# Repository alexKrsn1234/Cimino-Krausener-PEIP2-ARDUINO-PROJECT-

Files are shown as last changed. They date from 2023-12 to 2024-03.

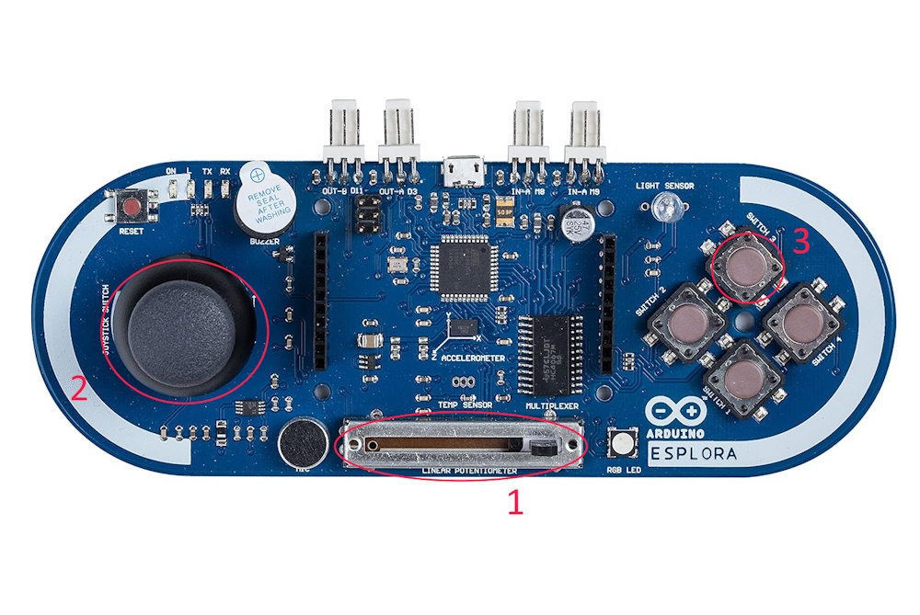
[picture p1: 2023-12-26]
documentation/Esplora Doc/images/esplora_buttons.jpg

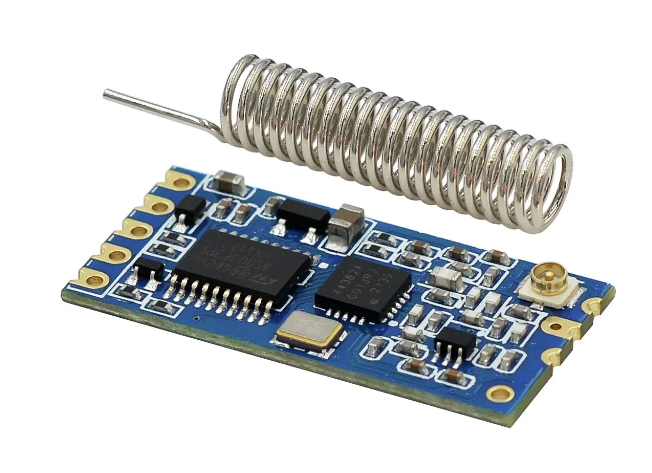
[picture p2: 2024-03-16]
documentation/HC-12 Doc/front.png

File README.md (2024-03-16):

# Cimino-Krausener-PEIP2-ARDUINO-PROJECT-
Ce projet est mené dans le cadre de la formation de PEIP2 de Polytech Nice-Sophia

## Cahier des charges
### Description: 
                  Voiture télecommandée rapide de type "RC Car".  
### Caractéristiques: 
                  -Roues avants directionelles
                  -4 roues motrices
                  -télécommunication RC

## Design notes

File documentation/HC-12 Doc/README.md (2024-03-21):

## QUICK HC-12 DOCSHEET


### PINS
   

Les pins VCC et GRD servent sans surprise à l'alimentation des modules.   
Les pins TXD et RXD eux permettent l'envoie d'information à travers le module.   
Le pin SET est utilisé pour configurer le module(mode, fréquence...).   

### CONFIG
Après avoir mis le pin "SET" à la masse, le module devrait être dans le mode "AT" prêt à recevoir les informations afin d'être paramétré (féquence, baud rate...)
Les différentes commandes utiles sont:   
  AT+Bxxxx pour modifier le baud-rate   
  AT+Cxxx pour modifier la chaine et ainsi la fréquence sur laquelle le module communique   
  AT+FUx pour modifier le mode de communication (délai d'envoie de bits, distance max de communication et optimisation de l'utilisation d'énergie)

### [Une documentation complète ici](https://statics3.seeedstudio.com/assets/file/bazaar/product/HC-12_english_datasheets.pdf)   

### [exemple d'utilisation trouvée sur le net](https://howtomechatronics.com/tutorials/arduino/arduino-and-hc-12-long-range-wireless-communication-module/)

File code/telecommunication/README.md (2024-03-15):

### Comment la télécommunication est-elle assurée ?

Celle-ci est assurée par les modules émetteurs/récepteurs Radio Fréquence HC-12. Ces modules se présentent comme ceci:   


Un des modules est placé sur l'arduino émetteur et l'autre sur l'arduino récepteur.
Le but final est d'envoyer le minimum d'informations afin d'éviter tout problème de surcharge des canaux, perte d'information... Il s'agit alors d'envoyer une 
valeur de vitesse visée de la voiture (roll) et de direction (direction)
L'ensemble des calculs nécessaires à la récupération de ces valeurs sont ainsi effectués côté émetteur avant leur envoi.
Les informations sont ensuite encodées au moment de l'envoi c'est à dire qu'elles sont serties de différents bits de contrôle.

Une fois réceptionées par l'arduino récepteur ces informations sont décodées et les valeurs reçues de roll et direction sont redirigées vers les pont en H. 

##### Détails techniques

fréquence: 433.4 MHz   
channel: 001   
baudrate: 9600

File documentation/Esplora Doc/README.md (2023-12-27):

# QUICK ESPLORA DOC SHEET

* ## Pins to use :  



* ## [Library](https://docs.arduino.cc/retired/archived-libraries/EsploraLibrary) to use.

* ## Buttons to use :  



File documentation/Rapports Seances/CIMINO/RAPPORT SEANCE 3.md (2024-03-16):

### Ce rapport est particulièrement long car il contient également le travail réalisé pendant les vacances de noël

# I/Travail réalisé pendant les vacances

##  I.1 MODULES HC-12

Découverte des modules et de leur fonctionnement, reconfiguration de ceci grâce aux commandes AT afin de communiquer sur une certaine fréquence(choix du canal)
à une certaine vitesse(baud rate) et du mode de fonctionnement(maitre/esclave, emmeteur/recepteur...).
Nombreux tests de communication effectués afin d'acquérir l'expérience nécessaire et de choisir un mode de fonctionnement paraissant adapté (les 3 premiers test 
ont étés réalisés sur 2 arduino uno (emmeteur/récepteur).
  1. envoie d'un bit d'information (0 ou 1)
  2. [contrôle à distance d'une led](/code/telecommunication/HC-12/HC12%20tests/ledtest)
  3. [envoie d'informations avec des bits de contôle (start, end)](/code/telecommunication/HC-12/HC12%20tests/TEST3)
     
  Emmetteur maintenant placé sur une Arduino Esplora   
  
  4. [envoie d'informations depuis le joystick de l'esplora](/code/test/car%20tests/esploratest/Joystick%20test)
  5. [envoie d'informations correctement encodées (bits de contrôles + bits liés au module d'envoie) à l'arduino uno du récepteur](/code/test/car%20tests/esploratest/Cytron%20motor%20test)

## I.2 HC-12 ET ESPLORA ET VOITURE

Définition d'un algorithme d'envoie/réception des données pour éviter les confusions.
Les valeurs envoyées sont les suivantes : Roll (enclenche le roulage du véhicule en fonction de la valeur de -255 à 255), Direction (décide de la valeur
de l'angle donnée aux roues avant de -255 à 255) et Communication (démarre une vérifiaction de la connexion).   

Les valeurs de Roll et de Direction sont calculées à l'aide des input de l'utilisateur. Ces calculs sont donc réalisés avant même l'envoie des données 
afin de priviliéger un envoie d'informations plus compacte.    

Ainsi, comme dans le [test 5](/code/test/car%20tests/esploratest/Cytron%20motor%20test), la valeur de roll est fonction de l'inclinaison du joystick(2) en Y et du slider(1), la valeur de direction dépend uniquement de l'inclinaison du joystick(2) en X.    

Ce sont ces données qui sont ensuite envoyées à l'arduino de la voiture par les modules RF HC-12.
Chaque envoie de données de l'esplora est certi de 2 bits de contrôle 's'(start) et 'e'(end) ainsi qu'un bit de séparation 'd'. 

Un envoie de données ressemble par exemple à "s120d58e", avec 120 pour la valeur de roll et 58 pour celle de direction.   

Une fois ces données reçues, l'HC-12 placé sur l'arduino de la voiture transmet ces données à l'arduino qui les "décrypte" et envoie l'infomation
nécessaire au pont en H qui contrôle les moteurs. Pour reprendre l'exemple précédent on demande au pont en H d'envoyer 120 au moteur 2 qui contôle 
la vitesse de la voiture et 58 au moteur 1(servo).  

La voiture semble lente, il faudra tester avec 2 ponts en H fonctionnels car je pense qu'avoir mis les 2 moteurs responsables de la vitesse de la voiture
sur la même sortie du pont en H divise le courant sortant de celui-ci en 2 (moteurs placés en parrallèles). Cela semble avoir un impact non négligeable
sur la puissance électrique reçue par les moteurs (divisée également par 2) et ainsi diminuant leur performance.

## I.3 POINTS A AMELIORER:

### 1. vitesse de la voiture:   

  Hypothèse: mettre 2 pont en H ou envoyer plus de patate

### 2. télécommunication:    

  -De nombreuses données semblent être perdues lors de la télécommunication   
  Hypothèse: Jouer sur les réglages des modules HC-12 afin de gagner en performance   
             Mettre des capacités en amont des modules comme recommandé   
             Changer de modules...    
             
  -Créer une vérification de la communication pour voir lorsque des données sont perdues (allumage led esplora)

### 3. branchements:
  -Réaliser des soudures pour simplifier les branchements réalisés et éviter les faux-contacts.   

## I.4 CREATION DE PLANS DANS LE BUT DE REALISER NOTRE PROPRE CHASSIS  

Nous avons décidé de prendre de l'avance sur la potentielle suite du projet en commençant à réaliser des plans 3D du futur chassis sur OnShape.
Alexandre réalisera l'ensemble de la partie transmission (Engrenages moteur, axe...) et les "suspensions" tandis que je tenterai de réaliser le bloc
chassis ainsi que l'aspect directionnel.

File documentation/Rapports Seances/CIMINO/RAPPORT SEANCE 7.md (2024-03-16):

## BUT DE LA SEANCE:
Le but que je m'étais fixé lors de cette séance était d'isoler la panne rencontrée la semaine dernière et de parvenir à la contourner.
Pour revenir un peu sur la panne, la voiture ne réagissait pas malgrè la bonne réception des données de la télécommande (côté emmeteur), il s'agissait donc
d'un problème côté voiture (code jusqu'à présent théorique, branchements ou composant(s) deffectueux). 

## TRAVAIL REALISE LORS DE LA SEANCE:
Afin d'isoler cette panne j'ai donc décidé de tester l'ensemble de la partie côté recepteur (code, branchements et composants). Afin de ne pas rajouter une potentiel nouvelle panne
j'ai décidé de ne pas travailler avec la télécommande mais d'implémenter directement le code nécessaire aux tests sur l'arduino de la voiture.
### Partie code:
Pour être sûr de la fiabilité de mon code, j'ai analyser chaque ligne de mon code ainsi que leur but et comparer avec le code de la séance de travail effectuée 
au cours du 1er semestre avec les ponts en H LN298N. Aucun problème de semblait venir du code. Les bons usages étaient respectés ainsi que les bonnes 
procédures. J'ai pu tester les fonctions [du code](/code/test/car%20tests/esploratest/L298n%20motor%20test/receiver/receiver.ino) sur une autre voiture et celui-ci fonctionnait convenablement. Le bug ne venait donc pas du code.

### Partie branchements et composants:
Dans le but de tester mes branchements et mes composants j'ai utilisé un multimètre principalement en tant que voltmètre afin de tester les tensions aux bornes de
ceux-ci. J'avais déjà des indcations visuelles (carte arduino bien alimentée car diode de contrôle alummée). J'ai alors testé les tensions en entrée et en sortie 
des ponts en H en implémentant des codes simples (ex : avancer en continue à fond, on est censé récupérer un haut voltage en sortie (out1,out2), le même qu'en entrée sur 
la patte enable. Lors de ce test je me suis rendu compte que les ponts en H étaient obsolètes. Ils ne fonctionnaient pas ou plus (impossible à déterminer) étant
donné qu'on avait jamais su les faire fonctionner (soit parce qu'ils étaient obsolètes initialement ou car nous les avions rendu hors service suite à une mauvaise
utilisation au départ). J'ai alors demandé de nouveaux ponts en H et était très précautioneux. Après les avoir branchés correctement (non sans mal car il s'agit 
d'un vrai travail d'orfèvre), j'ai réalisé à nouveau des tests qui se sont avérés fructueux. La panne provenait seulement des ponts en H. Nous pouvons reprendre 
l'avancement du projet.

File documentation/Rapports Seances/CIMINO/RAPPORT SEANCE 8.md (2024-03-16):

## TRAVAIL REALISE:
Lors de cette séance, je me suis attelé à faire fonctionner la voiture. Lors de la séance précédente nous avions résolu le bug qui empêchait la voiture de se
déplacer. Cette fois ci j'ai donc réalisé tout les branchements nécessaires pour l'utilisation des 2 ponts en H et j'ai donc testé le [code théorique](/code/test/car%20tests/esploratest/L298n%20motor%20test/receiver/receiver.ino)
réalisé il y a 2 seances auquel j'ai rajouté une fonction pour tourner. Le test se faisait donc à distance à l'aide de la télécommande. Le test a dans l'ensemble
porté ses fruits mais on a pu constaté certains bugs:   
  -La voiture n'a pas le même comportement en marche avant et en marche arrière.

  -Elle est capable de tourner que d'un seul côté.

  -Elle n'est pas capble de réaliser une marche arrière à pleine puissance.

  -Elle peut difficilement avancer et tourner en même temps.

Nous avons donc chercher des solutions pour palier à ces problèmes. Alexandre s'est penché sur la question et vous trouverez ses recherches dans son rapport de
séance. Finalement après de nombreux essais infructueux, nous avons décidé de charger pleinement la batterie (elle était à ~3,8V par cell) jusqu'à ~4,2V par cell.
Il semble alors que cette recharge soit la solution au problème. Une solution qui semble toutefois partielle car nous aimerions dans l'idéal que la voiture
remplisse ses fonctions pendant un maximum de temps d'utilisation. J'ai alors procédé à des tests pour déterminer jusque quel voltage la voiture est totalement 
opérationnelle. Cette valeur est atteinte pour METTRE LE VOLTAGE. Nous en avons donc conclu que METTRE UNE CONCLUSION.

J'ai également décidé de créer une pièce qui servirait de support pour placer l'ensemble de nos composants (jusqu'à présent plus ou moins bien entassés sur 
le chassis de la voiture) afin de rendre un travail plus propre et avec moins de risque de casse(faux-contacts...).

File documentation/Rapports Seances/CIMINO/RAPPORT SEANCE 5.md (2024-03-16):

## I/ Partie pratique et résumé:
Cette semaine mon travail consistait pleinement à mettre en fonctionnement la voiture avec la nouvelle batterie et les nouveaux ponts en H confiés pour l'occasion.   



Nous sommes passés d'une batterie 2 cells(7,4V) à une 3 cells(11,1V) dans le but d'acquérir plus de puissance. Cette batterie envoyant un débit plus élevé il s'agit
donc de mettre à l'épreuve de nouveaux ponts en H car le précedent devenait ainsi obsolète. Nous possédant désormais 2 ponts en H montés sur leur module LN298N.
Pour la sélection des ponts en H et de leur nombre nous avons effectué des test d'ampérage en entrée des moteurs. En roulage avec resistance infligée afin de 
simuler les forces de frottement et le poids de la voiture s'opposant au mouvement on obtient pour une tension d'entrée de 5V un ampérage totale en entrée des 
moteurs d'environ 2 ampères. Les modules LN298N pouvant sortir jusqu'à 1,2 ampères sans compromettre la sécurité, j'ai donc choisi d'utiliser 2 ponts en H.
Le premier s'occupera de la motorisation des roues et l'autre de la direction et du potentiel futur bras dont la création repose sur Alexandre.

Afin de pouvoir alimenter ces 2 ponts en H à l'aide d'une seule batterie, J'ai soudé à chaque fil + et -d'un connecteur XT60 qui sera relié à la batterie
2 fils qui se connecteront chacuns à leur borne respective des LN298N. Les ponts en H sont ainsi connectés en parrallèle à la batterie et alimenteront ensuite
les moteurs.   



## II/Partie code:

Afin de finir la mise en place de ces nouveux composants, j'ai réalisé le code théorique pour commander les moteurs de la voiture après avoir installé 
une librairie permettant de se servir facilement des fonctionnalités du LN298N. Cependant, je n'ai pas pu vérifier le bon fonctionnement du code (cf III).

## III/Problèmes rencontrés:

Il semblait à première vue que la batterie qui nous avez été confiée etait Hors Service. En effet après l'avoir mise en charge nous avons voulu la connecter 
afin de tester nos avancées, cependant elle ne fournissait pas le courant nécessaire pour alimenter l'arduino depuis le Pont en H. ALors j'ai testé son voltage
et celui-ci était de seulement 3V au lieu de 11,1 en moyenne. Après quelques recherches (étude de graphe du potentiel d'une 3 cell) j'en ai conclu que celle-ci
était hors d'état de service. J'ai donc demandé une autre batterie mais lors de la mise en charge, le même problème apparaissait c'est à dire que 
les leds du chargeur fournit clignotait en rouge, hors ce clignotement n'est même pas renseigné sur la docsheet du chargeur. La batterie ne charge pas.
Je me questionne donc sur l'état du chargeur et sur sa bonne compatibilité avec les batteries utilisées. Je n'ai pas résolu ce problème. Je tacherai de le 
résoudre avant la prochaine séance.

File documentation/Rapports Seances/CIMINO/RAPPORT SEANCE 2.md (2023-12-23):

#      SEANCE DU 22/12/2023 

Lors de cette séance j'ai été occupé par l'aspect télécommunication que recquiert notre projet. Il s'agissait alors de paramétrer les modules HC-12
qui nous ont étés confiés afin de réaliser la liaison entre la télécommande (Arduino esplora) et la voiture (commandée par l'arduino UNO).


J'ai alors paramétré les modules afin qu'ils communiquent sur les mêmes fréquences et qu'ils possèdent la même vitesse de transmission grâce aux commandes AT.
   
  -paramétrage de la vitesse de transmission entre les 2 modules:
    AT+Bxxxx avec xxxx vitesse de transmission des informations. J'ai choisi la valeur de 9600 bauds car je ne pense pas qu'utiliser 
    une valeur élevée soit une bonne idée, on risque de surcharger le canal et les cartes arduino alors que les moteurs de la voiture ne pourront pas suivre
    l'ensemble des ordes données à une telle vitesse car ils sont assujettis à une certaine inertie (je pense qu'il vaut mieux leur donner des valeurs "lissées 
    dans le temps"). Cette valeur pourra être modifier en fonction des résultats des expérimenttaions menées. 
  
  -paramétrage de la fréquence utilisée pour communiquer réalisé en choisissant la chaine sur laquelle communiquer:
    AT+Cxxx avec xxx numéro de chaine allant de 001 à 100 (001 correspond à une fréquence d'émission/réception de 433,4MHz elle augmente de 400KHz
    par augmentation de chaine). J'ai choisi arbitrairement le channel 050 mais encore une fois cette valeur pourra évoluer au cours du temps en fonction de 
    l'analyse empirique de la qualité de la télécommunication.

Ensuite, le but était de faire communiquer les 2 modules à distance.

Pour cela je me suis renseigner sur la documentation peu fournie du HC-12 pour établir un code établissant cette communication et la vérifiant.
Le but était d'envoyer des bits d'information 0 ou 1 d'un module à l'autre et de retranscrire les informations reçues sur le moniteur série de l'IDE Arduino.
Cependant malgrè de nombreuses tentatives, je n'ai pas réussi à faire passer une information d'un module à l'autre, je m'y atèlerai donc pendant les vacances.

Je suis alors parvenu à un programme à tenir avant la séance du 12 janvier:
* établir la communcation entre les 2 modules
* établir un protocole perfectionné d'envoie des bits pour envoyer des informations plus complexe sans confusion de données.
* connecter correctement un des modules à la télécommande (Arduino esplora) et récupérer conformément au protocole établie précedemment les informations
entrées par l'utilisateur de la télécommande.
* envoyer ces informations à l'autre module placé sur l'arduino uno (qui sera sur la voiture) selon le protocole.
* transférer les donées reçues et effectuer les actions demandées (donc nécessite un codage des informations selon le même
protocole définit précedemment).

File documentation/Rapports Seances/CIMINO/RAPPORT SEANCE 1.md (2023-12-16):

# SEANCE 1 (15/12/2023)
Après avoir terminé de définir clairement notre projet et nous être penché sur les performances que devront atteindre notre voiture (vitesse visée 50km/h).
Après également nous être renseigné sur la manière la plus optimal de réaliser la transmission arrière (point de départ de nos recherches) nous en avons déduit selon le raisonnement suivant:

Vvisée = 50km/h ~ 14m/s
diamètre roue D ~ 4,5 cm
1 tour de roue T= 2πR = πD = 4,5π cm ~ 14,1cm
Vroue = D/T ~ 100tr/s
gear ratio estimé : G=2 (2 tour de moteur pour 1 tour d'axe de transmission)
donc Vmoteur ~ 200 tr/s ~ 12000 tr/min

Il s'agissait donc de trouver une bonne combinaison batterie/moteur afin de faire tourner le moteur à environ 12000 tour par minutes.
Etant donné que nous ne sommes pas en mesure d'estimer les forces de frottements lors du roulage ainsi que le poids de la voiture nous avons pris la décision de prendre de la marge vis à vis des puissances des moteurs et des spécifications des batteries lors de nos recherches.

Lors de cette séance nous donc avons activement continuer les recherches (démarrées aupréalable) concernant les pièces dont nous  avons besoin pour mettre à bien notre projet.
Après avoir trouvé [batterie](https://www.amazon.com/dp/B08FM2MVNF/ref=emc_b_5_t), [servomoteur](https://www.amazon.com/gp/product/B07S9XZYN2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) et [esc](https://www.amazon.com/HOBBYWING-QUICRUN-10BL120-SENSORED-Touring/dp/B0765Q2SVS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,toys-and-games,116&sr=1-1&linkCode=sl1&tag=jinanprojec05-20&linkId=b2c1cea7d683851db009dc4553eaadb7&language=en_US&ref_=as_li_ss_tl), de mon côté nous avons mis en commun notre travail avec Alexandre pour discuter de nos choix de pièces et avons ensuite demander aux professeurs de passer commande. Le choix (définitif) de ces pièces nous permettait de nous lancer directement dans l'élaboration des plans du chassis (ainsi aux dimensions dictées par les composants).

Cependant Monsieur Masson a mis fin à nos espoirs en nous conseillant de travailler sur une voiture toute faite qu'il à mis à notre disposition.


L'idée initiale était de se concentrer uniquement sur l'aspect développement de notre voiture SEULEMENT sans inclure la partie télécommunication que nous comptions prendre "déjà réalisée".
Mais cette redirection nous pousse à abandonner l'ensemble de la partie conception et de nous rediriger sur les mouvements de la voiture et la télécommunication uniquement...

Il nous a donc été confié une Arduino [Esplora](https://docs.arduino.cc/retired/boards/arduino-esplora) afin de réaliser la télécommande ainsi qu'une paire d'emmeteur/recepteur.
Nous avons ensuite testé les moteurs de la voiture 1 par 1 afin de vérifier qu'ils fonctionnaient bien.

Cette redirection de projet innatendue nous a poussé à nous sortir de nos plans et de réenvisager l'ensemble de la suite du projet. Nous n'avons pas eu le temps d'aller plus loin dans notre réflexion lors de la séance. Cependant nous pensons qu'il est envisageable de terminer ce projet dans de courts délais afin de potentiellement revenir sur le projet initial.

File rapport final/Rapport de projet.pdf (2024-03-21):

# Rapport de projet: La voiture qui va vite

Un projet porté par Alexandre Krausener et Théo Cimino

## I/Objectifs du projet

L’objectif général du projet est de réaliser une voiture télécommandée dite « RC Car » qui roule à une vitesse élevée et qui a pour finalité d’être ludique. Il s’agit d’un jouet facile à utiliser afin de pouvoir plaire au plus grand nombre.
Afin de mener à bien ces objectifs nous avons défini un cahier des charges dans lequel des critères plus précis sont consignés.

I.a/Cahier des charges:
La voiture présente 4 roues motrices, dont 2 roues directrices (roues avants) et est télécommandée à longue distance. L’usage de la télécommande est intuitif et simple.

I.b/Objectifs associés:
Ce projet est l’opportunité pour nous de nous lancer dans la conception complète d’un produit, il nous offre la possibilité d’acquérir de l’expérience et de sérieuses compétences concernant l’organisation, la mise en œuvre et la réalisation d’une idée, en plus de développer nos talents en robotique.

## II/Plannings

Lors de la première séance nous avions conçu un planning prévisionnel afin d’anticiper et d ’évaluer le mieux possible les étapes de conception en terme de temps et d’investissement afin de proposer un déroulement idéal et optimisé du projet. Cependant malgré nos nombreux efforts tant à la conception de ce planning qu’à la réalisation de la voiture, celui-ci s’est avéré erroné et présente de multiples différences avec le planning final. Veuillez trouver ci-dessous les 2 plannings en question.
II.a/Planning prévisionnel: | II.b/Planning final:

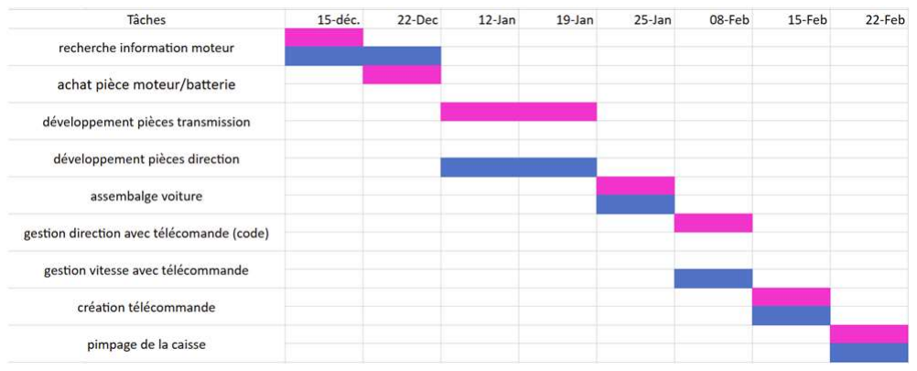
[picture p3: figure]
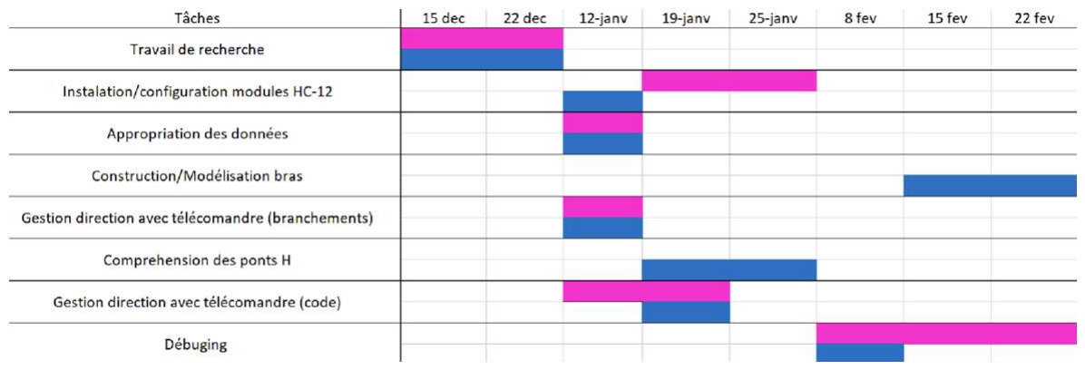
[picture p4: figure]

Les principales différences proviennent du fait de la redirection du projet, en effet, au départ nous comptions concevoir la voiture entièrement c’est-à-dire le châssis également. Cependant, la conception de ce châssis nous a été refusé alors toutes les tâches qui en découle ont été supprimées. De plus nous avons grandement sous-estimé la part de correction des erreurs et de débuging dans le planning prévisionnel.

## III/Fonctionnement de la voiture

III.a/Matériel utilisé
Le matériel auquel nous avons eu recours pour la réalisation du projet est le suivant: -1 châssis de voiture télécommandée -1 batterie 3 cells (11,4V) 2200mAh
-3 moteurs à courant continue
-2 pont en H
-2 modules émetteur/récepteur Radio Fréquence -1 Arduino uno
-1 Arduino esplora (télécommande) III.b/Schémas d’utilisation de la télécommande

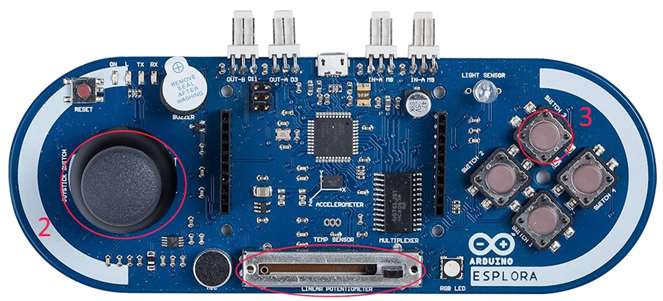
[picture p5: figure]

1: potentiomètre permettant de réguler la puissance des moteurs (20 à 100%)
2: joystick permettant de contrôler les mouvements de la voiture
3: bouton de vérification de l’état de la connexion entre la télécommande et la voiture

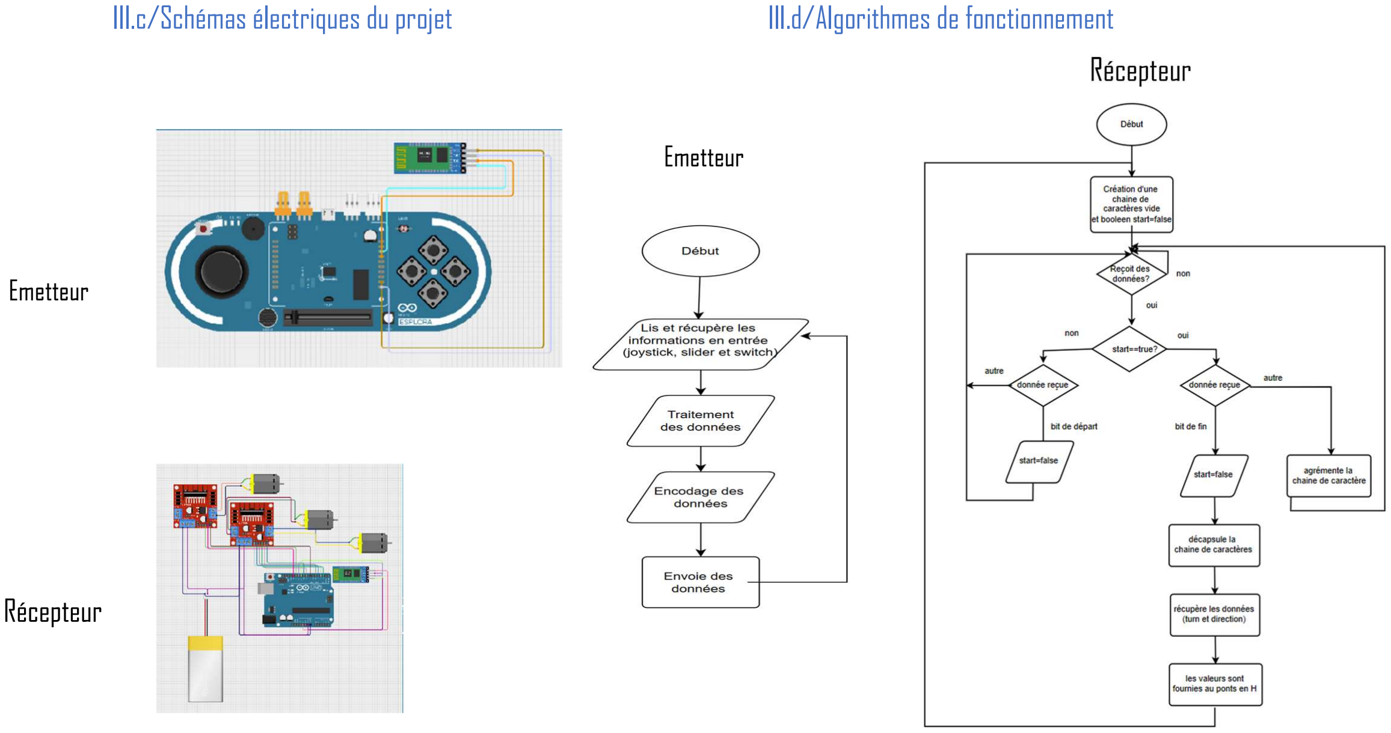
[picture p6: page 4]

III.c/Schémas électriques du projet | III.d/Algorithmes de fonctionnement

Emetteur

Emetteur

Récepteur

## IV/Estimation du coût

IV.a/Coût des composants et du matériel

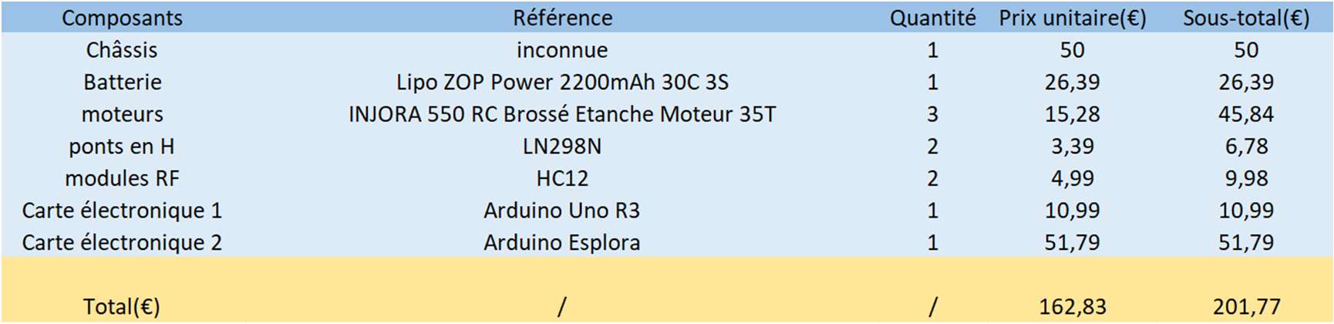
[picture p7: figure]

IV.b/Estimation de la masse salariale (Salaire d’ingénieur de 23€ de l’heure)

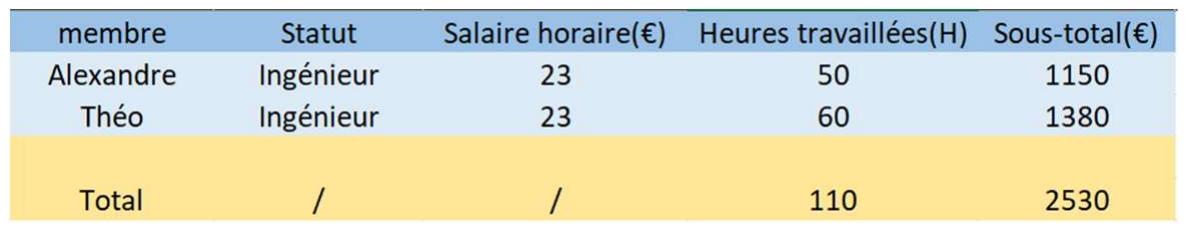
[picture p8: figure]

IV.c/Coût total
A l’aide de ces informations, le coût total est estimé à environ 2732€.

## V/Conclusion

V.a/Problèmes rencontrés
Le premier problème que nous avons rencontré est lié à l’obsolescence des drivers ch340 qui permettent la communication entre le pc et l’Arduino. En effet nous avons perdu de nombreuses heures à rechercher et réinstaller ces drivers quelque peu capricieux. Par la suite nous avons également étaient confrontés à de nombreux bugs après avoir décidé de changer l’alimentation de la voiture et ainsi de passer d’une batterie 2 cells à une 3 cells. Ce changement nous a valu d’augmenter le nombre de pont en H et de les changer ainsi de réadapter tout notre système d’alimentation. Ces changements ont induits de nombreux bugs tant informatiques (réécriture partielle des codes) que physique (courts circuits, batteries défectueuses…)
Malgré tout nous sommes parvenus au bout de ce projet. C’est-à-dire que nous avons conçu (mis à part le chassis) une voiture télécommandée dont le pilotage est simple et intuitif atteignant la vitesse astronomique de 10km/h sur le plat (alors imaginez en descente!!).
V.b/Perspectives envisagées
Dans le cas où il nous serait donner 8 semaines additionnelles pour continuer le projet il serait possible d’envisager au
moins 2 améliorations. Nous finaliserions certainement la conception de la pince (qui permet d’attraper des objets) que nous avions déjà envisager en fin de projet et nous nous pencherions également sur l’optimisation et la propreté de la conception c’est-à-dire d’envisager de créer nos propres PCB par exemple. Une autre perspective serait de tenter de concevoir le châssis de la voiture nous-mêmes comme initialement prévu. Ou même réaliser les PCB et le châssis pourquoi pas?

## VI/Bibliographie

L’ensemble de la bibliographie et des ressources utilisées se trouvent dans le dossier « documentation » du projet sous forme « nanani »Doc.

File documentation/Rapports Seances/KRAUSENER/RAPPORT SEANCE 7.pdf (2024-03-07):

RAPPORT SEANCE 7 :

Durant cette séance nous avons enfin réussi à faire avancer la voiture. En effet, en ayant changé la batterie, le pont en h n’était plus suffisant. Ainsi, nous avons dû tester les ponts en h car ils ne fonctionnaient pas correctement. Nous les avons donc branchés a la batterie et testé avec un voltmètre. Ils ne fonctionnaient pas du tout. Ainsi, M. Rallo nous en a donné d’autre et la voiture roule à nouveau !

De plus j’ai aussi avancé les plans du bras. Beaucoup de problèmes techniques concernant des mauvaises mesures ont donc étaient réglés (comprenant aussi la pièce imprimé la semaine dernière).

La semaine prochaine (dernière séance) il faudra imprimer toutes les pièces qui constituent le bars afin de le monter et de gérer branchements, assemblage et code.

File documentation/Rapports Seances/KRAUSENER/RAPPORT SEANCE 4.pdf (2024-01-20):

RAPPORT SEANCE 4 :

Durant cette séance, nous avons commencé à voir quels sont les objectifs réalisables dans le temps impartie par rapport aux idées énoncées la semaine dernière (bras télescopique, système de suivi de ligne…).

Avec mon collègue, nous avons déjà réussi à programmer et installer un radar capable d’arrêter la voiture si un obstacle se trouve devant elle.

Pour ma part, j’ai étudié les possibilités de la construction d’un bras. J’ai d’abord pensé à un système de fil pour descendre le bras et pour actionner les pinces. Néanmoins, avec ce système, nous ne parviendrons pas à attraper des objets lourds car c’est uniquement le poids des pinces qui feront résistance.

J’ai donc pensé à
un autre système
basé sur le
principe du tirebouchon
permettant
d’avoir plus de
force pour
attraper les objets
lourds et bloquer
les pinces.

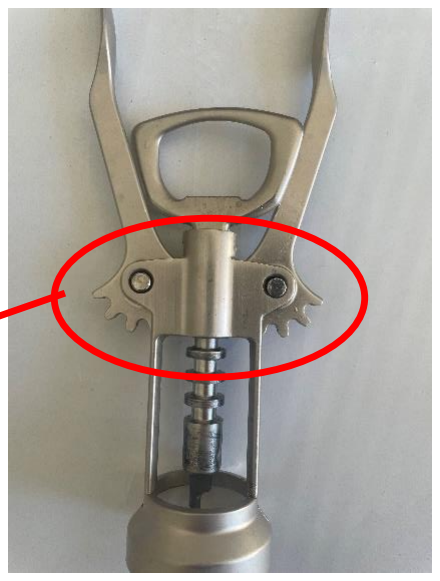
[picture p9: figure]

Il nous sera donc nécessaire d’avoir deux moteurs : un moteur classique semblable a celui qui gère la vitesse des roues et un piston qui gèrera les pinces.

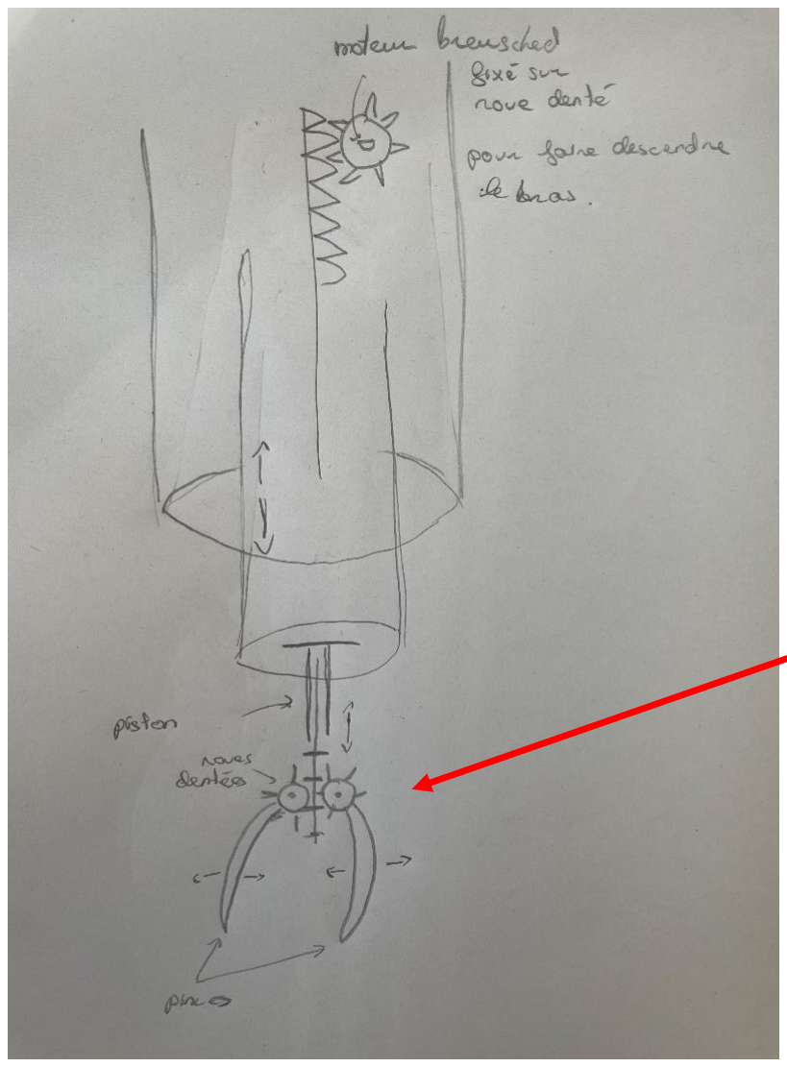
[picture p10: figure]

Le problème qui se pose est que désormais, trop de modules sont connectées au pont H, nécessitant alors trop de demande en tension. C’est pour cela que l’on nous a confié une batterie de 11,1 V. Mais, le pont H qui nous a été fournis n’accepte que du 9,5V. Un pont H admettant une plus haute tension sera donc nécessaire pour respecter un des points cruciaux du projet : rouler vite.

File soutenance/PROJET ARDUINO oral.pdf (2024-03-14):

# PROJET ARDUINO : LA VOITURE QUI ROULE VITE

Krausener Alexandre

Cimino Théo

## Sommaire :

## - Nos objectifs, nos motivations

## - Matériel utilisé

## - Explication du fonctionnement

## - Planning

## - Conception du bras

## MOTIVATION :

## OBJECTIFS :

## PROBLÉMATIQUE :

- Sujet distrayant
- Découverte de quelque
chose que tout le monde
connais
- Développer une voiture qui roule vite
- Tout construire de A à Z
- Comment construire un châssis ?
- Comment gérer la communication ?

# MATÉRIEL

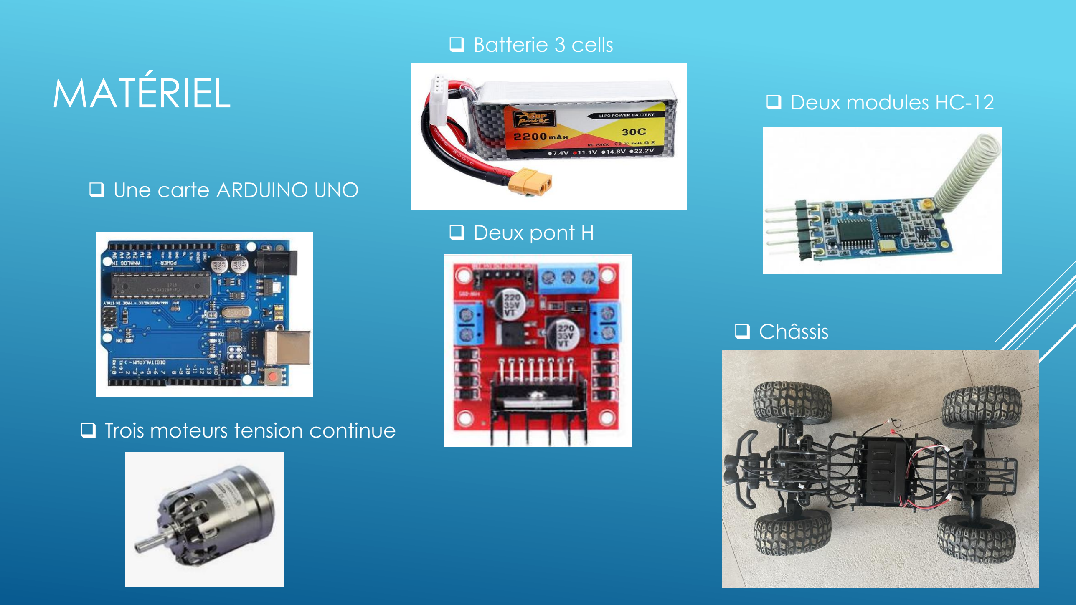
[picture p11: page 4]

❑ Une carte ARDUINO UNO

❑ Deux pont H

❑ Trois moteurs tension continue

❑ Deux modules HC-12

❑ Châssis

❑ Batterie 3 cells

# EXPLICATION DU PROJET

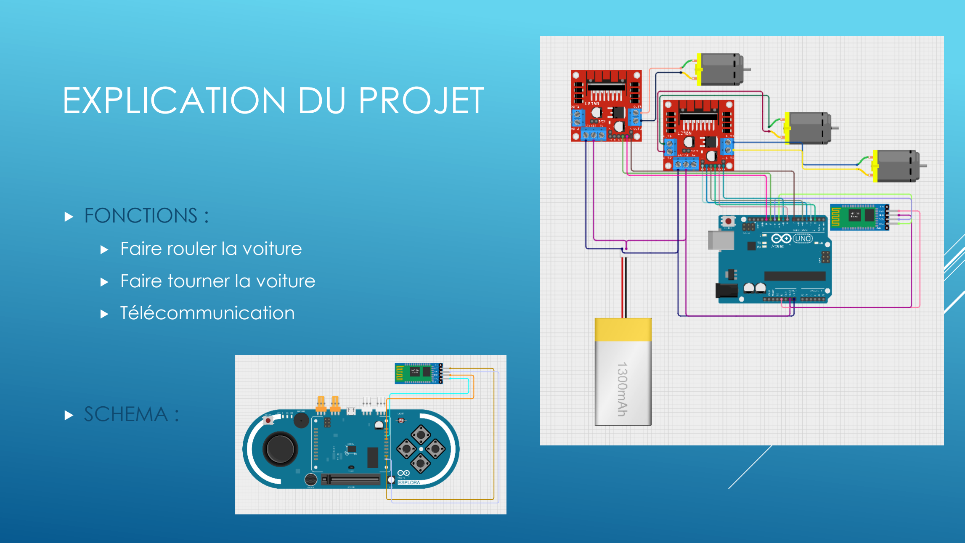
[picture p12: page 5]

- FONCTIONS :
- Faire rouler la voiture
- Faire tourner la voiture
- Télécommunication
- SCHEMA :

# PLANNING :

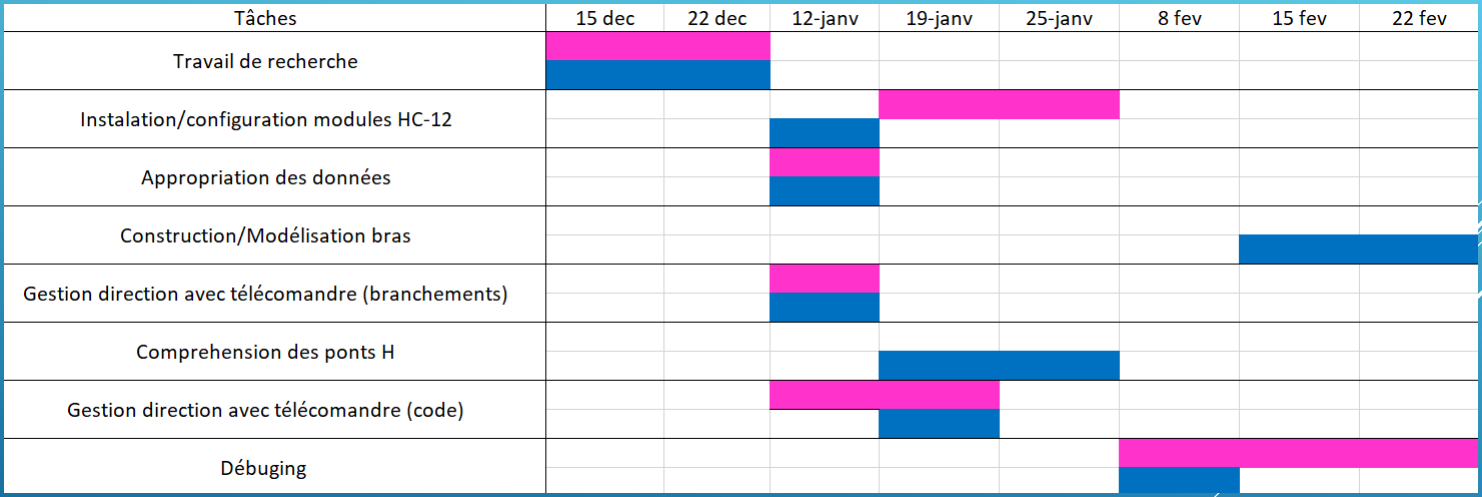
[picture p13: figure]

# CONCEPTION D’UN BRAS

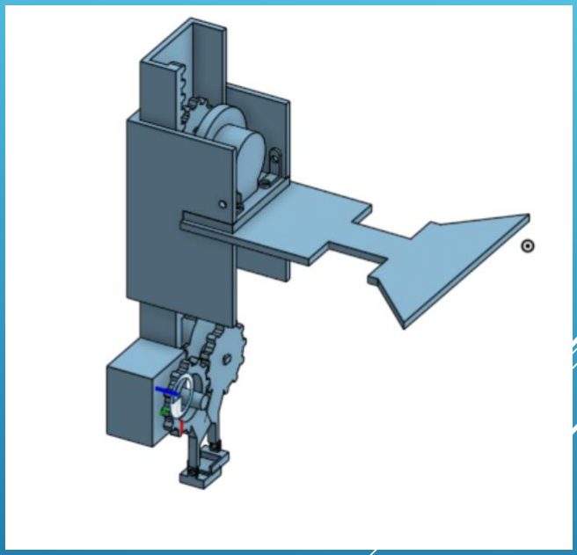
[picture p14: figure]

- Projet de bras : les deux dernières séances ont été consacrée à la conception d’un bras sur lequel est fixé une pince
1. Conception 3D
2. Impression 3D de certaines pièces

# CONCLUSION :

- C’est l’aboutissement d’un projet qu’on a porté pendant plusieurs semaines.
- On a développé nos compétences en Arduino, mécanique et en bricolage.
- On a appris à surmonter des difficultés et à renoncer à certaines idées non réalisables

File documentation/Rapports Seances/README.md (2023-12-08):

Ce dossier contient l'ensemble des rapports de séance de chacun des membres du binôme.

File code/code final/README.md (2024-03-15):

#### TADAAAA...Voici le dossier contenant les codes finaux, ceux avec lesquelles le projet est mené à bien (la voiture roule et vite)!

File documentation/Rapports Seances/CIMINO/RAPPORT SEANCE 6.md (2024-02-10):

## I/Problèmes rencontrés:
Les problèmes liés aux batteries fournies ont coûté plusieurs heures à l'avancement du projet. En effet, la première batterie récupérée avant la semaine de ski
s'est avérée être deffectueuse. J'ai pu la tester seulement au retour de la semaine de ski car je n'ai pas le matériel adapté chez moi et je n'ai pas pensé à le 
faire avant en cours (lors de la séance 5) pensant que le matériel ne serait pas deffectueux. Suite au test du voltage en sortie de la batterie, je me suis rendu 
compte qu'il ne sortait qu'environ 2,5V par cell contrairement à 3,7V minimum si celle-ci n'est que très peu chargée. J'ai alors demandé une autre batterie 3 cell
mais celle-ci posait le même problème, la rendant HS. Elle s'est même étonnemment déformée (gonflement anormal) la rendant dangeureuse (risque d'explosion).
La troisième batterie s'est avérée être en bon état. Mais la perte de temps est considérable. Tout le travail que je comptais réaliser pendant la semaine de ski
reposait sur l'utilisation de la batterie. Le projet a donc repris son cours lors de cette séance.

## II/Travail réalisé lors de la séance:
J'ai alors réalisé tout les branchements nécessaire pour tester le code théorique écrit à la seance précedente. Ce code visait à remplacer la version 1 du code 
fonctionnel côté recepteur car on a changer de pont en H en même temps que de batterie. L'ancien pont en H étaient obsolète pour une telle puissance délivrée (cf
RAPPORT SEANCE 5). Dans ce code j'ai utilisé une librairie conçut pour faciliter l'usage des ponts en H LN298, cependant malgrè les tests effectués, la voiture
ne se déplacait pas. En isolant le problème, je me suis rendu compte que les ponts en H ne délivraient pas la puissance aux moteurs. L'hypothèse est que le bug portet sur la librairie utilisée. J'ai donc décidé de ne pas utiliser cette librairie et de créer les fonctions dont j'ai besoin par moi même. J'ai donc codé
deux fonctions simple pour faire avancer et tourner la voiture en fonction des données reçues. Et j'ai remplacé les fonctions de la librairie par celles-ci. Le problème persiste cependant pour le moment.

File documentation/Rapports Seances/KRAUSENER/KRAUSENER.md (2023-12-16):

RAPPORT SEMAINE 1 (15/12/23) :
    Nous avons recherché plusieurs élements afin de réaliser notre projet. J'ai tout particulièrement recherché un moteur et commencé à comprendre comment celui-ci entrainait les roues. Dans l'optique de créer de toute pièce notre voiture RC, il fallait aussi s'interresser aux engrenages (la courroie de transmission), placés entre le moteur et les roues. J'ai alors cherché sur youtube comment certains avaient réussit à créer des voiture RC. Mais finalement, après avoir pris conseil auprès d'un enseignant, un chasis déjà fini nous à été confié. Nous avons donc déjà pu comprendre les branchements à effectuer sur notre voiture et commencé à coder pour aire avancer celle-ci.

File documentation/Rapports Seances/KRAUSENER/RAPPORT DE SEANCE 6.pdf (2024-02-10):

RAPPORT DE SEANCE 6

Durant cette semaine j’ai surtout travaillé sur les plans du bras robotisé.

J’ai ainsi déjà imprimé le support du bras (voir rapport séance 5) et avancé les plans.

Cette semaine, j’ai donc réalisé trois pièces supplémentaires : la courroie (indispensable pour faire monter et descendre le bras), la fixation pour cacher le moteur…) et l’engrenage pour faire la liaison entre le moteur et la courroie.

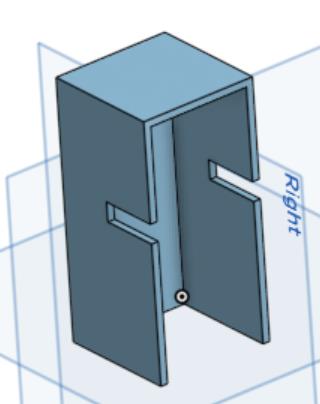
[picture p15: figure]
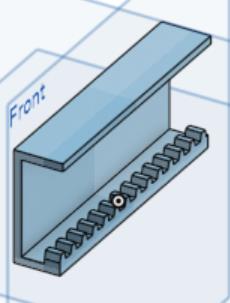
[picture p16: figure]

Assemblé, voici à quoi ça pourrait ressembler :

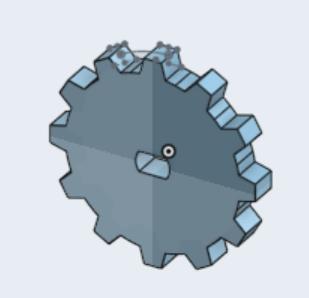
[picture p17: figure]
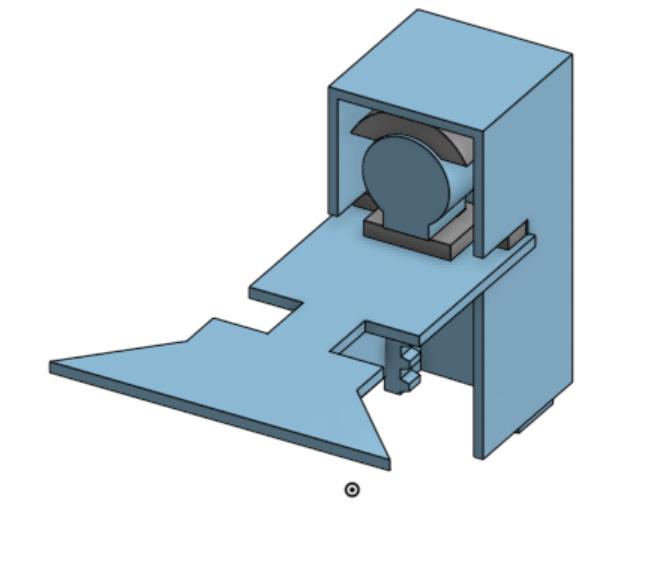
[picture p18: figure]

La suite du projet portera sur les pinces et le support pour le moteur les contrôlants ainsi que sur l’impression des différentes pièces.

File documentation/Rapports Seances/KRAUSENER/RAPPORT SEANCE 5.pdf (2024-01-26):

RAPPORT SEANCE 5

Durant cette semaine je me suis donc intéressé à la modélisation du bras et à sa conception.

J’ai tout d’abord expliqué mon idée à M. Masson qui m’a donc remis un moteur coup par coup pour faire baisser la courroie et donc faire baisser le bras. (Voir schéma séance 4)

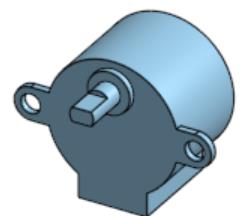
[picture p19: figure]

J’ai ensuite pu m’attaquer à la modélisation 3D sur le logiciel Onshape.

En cherchant sur internet, j’ai réussi à trouver des plans techniques du moteur et j’ai ainsi pu le modéliser en 3D avec les bonnes côtes sans difficultés.

J’ai ensuite cherché à savoir où je pouvais installer le bras et où placé la planche de maintient qui soutiendra la structure et les deux moteurs (moteur pas à pas et piston).

L’arrière de la voiture me semble un bon emplacement au vu de la place libre. C’est donc ce choix qui a donné lieu à la pièce que vous voyez ci-dessous. Comme des bouts de plastique gênent sur les côtés, j’ai donc dû prendre des mesures afin de faire des entailles à la structure pour qu’elle épouse parfaitement la forme de la voiture.

Bien sûr des perçages sont à prévoir pour fixer la structure à la voiture.

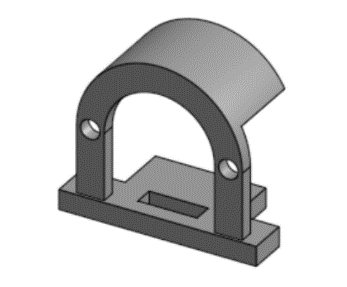
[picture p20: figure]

J’ai finalement aussi réalisé une pièce de fixation pour le moteur afin qu’il ne bouge pas lors du déplacement de la voiture. Vous pouvez également observer des trous sur la planche et l’accroche afin de faire passer les câbles du moteur.

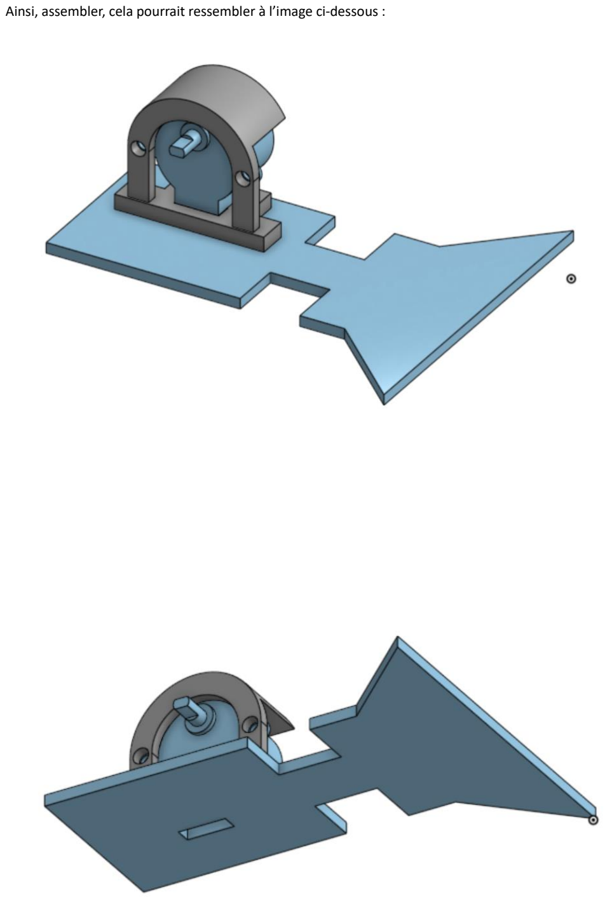
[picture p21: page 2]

Ainsi, assembler, cela pourrait ressembler à l’image ci-dessous :

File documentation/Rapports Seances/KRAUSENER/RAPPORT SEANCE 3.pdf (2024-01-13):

RAPPORT SEANCE 3 :

Durant les vacances, nous avons beaucoup progressé sur notre projet vu que notre voiture roule maintenant sans accros (Démo dans une petite stories Insta).

Un travail sur de multiples aspect à été fournis aussi bien par mon collègue que par moimême.

Pour ma part, je me suis concentré sur la manette ESPLORA et sa librairie associée.

La carte est relativement simple d’utilisation, mais, l’absence de documentation concernant les branchements des pins à rendu la tâche complexe.

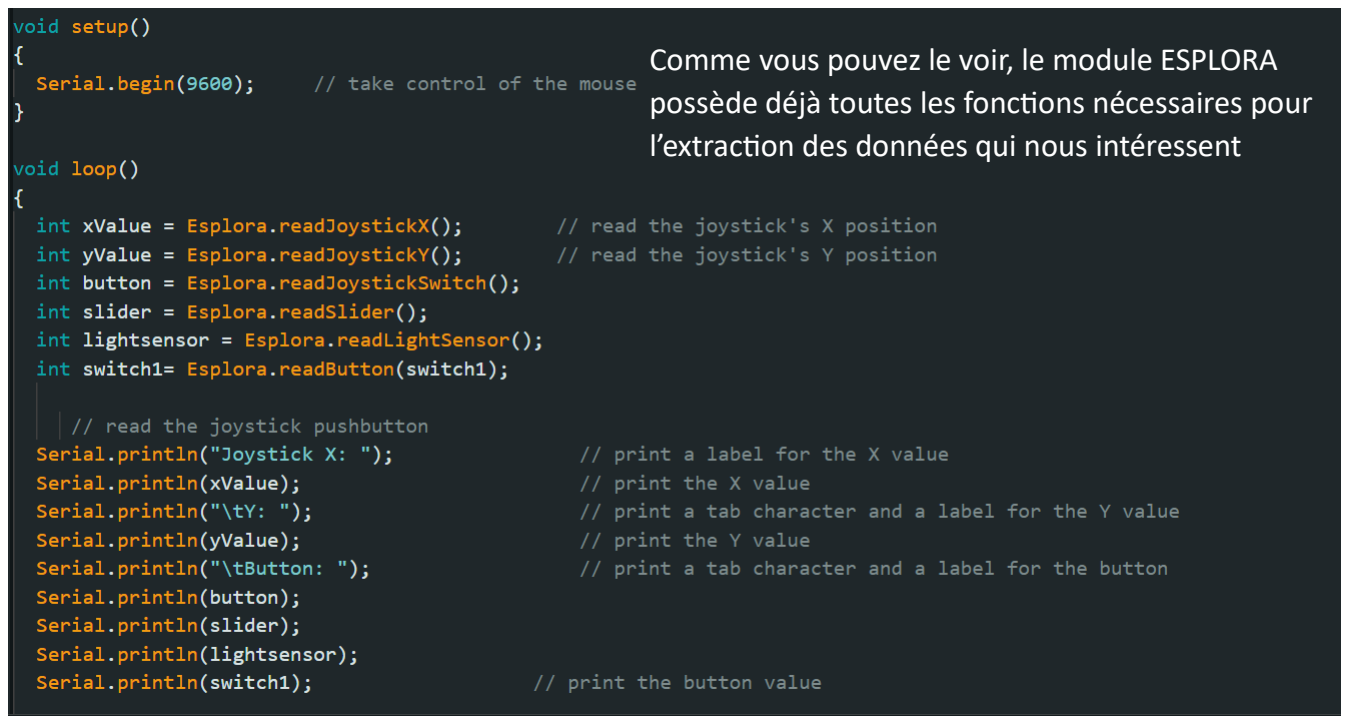
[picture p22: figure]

Après quelques recherches, j’ai trouvé une documentation non-officielle qui semble fonctionner.

J’ai donc ensuite procédé à des tests permettant de récupérer les informations données par les différents modules de la télécommande.

Voici les modules que nous allons utiliser :

1- Potensiomètre : ajuste la puissance délivrée aux moteurs
2- Joystick : gèrre la direction de la

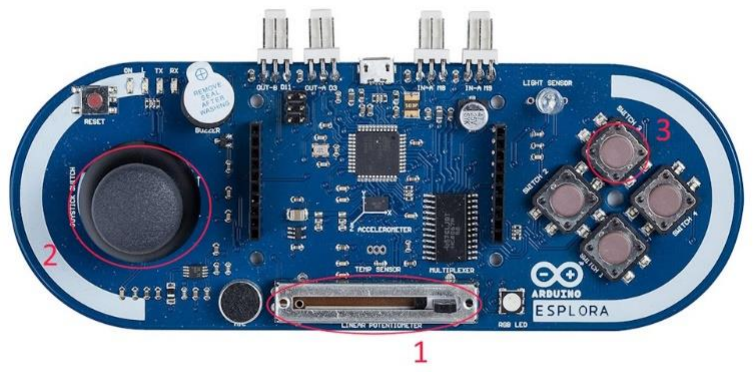
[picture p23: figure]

voiture
3- Bouton poussoir : verifira la connexion avec la voiture pour connaitre l’état de la transmission entre la télécommande et la voiture. (allumra une led si la connexion est bonne).

Comme vous pouvez le voir, le module ESPLORA possède déjà toutes les fonctions nécessaires pour l’extraction des données qui nous intéressent

Un câble management a aussi été réalisé pendant la séance grâce à des scratchs, diminuant alors drastiquement les faux contacts, problème qui a été relevé par mon collègue dans le rapport de séance 2.

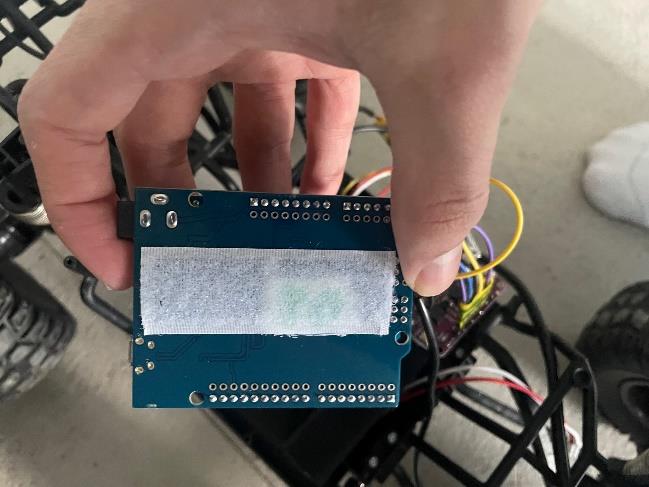
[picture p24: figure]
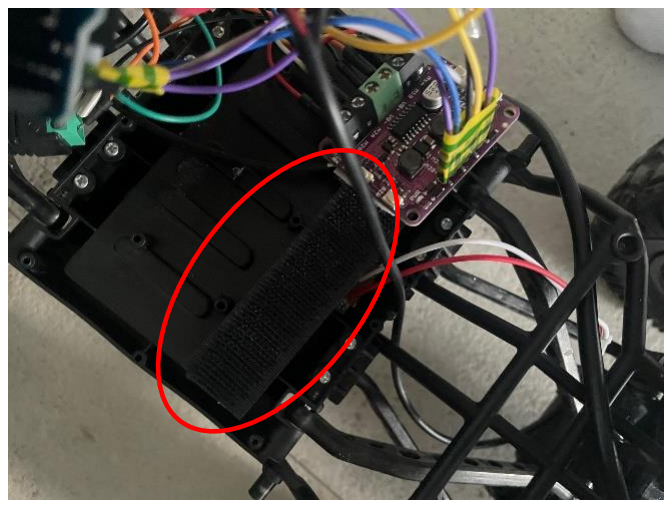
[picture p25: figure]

Durant la séance, un travail de recherche à été mené sur les possibilités d’amélioration de la voiture. En effet, vu qu’un châssis monté de toute pièce n’a pas été possible au vu du temps restant, plusieurs idées pourraient être implémentées dans les semaines à venir :

1- Système anticollision qui arrêtera la voiture si elle détecte un obstacle devant elle 2- Système de suivi de ligne pour une conduite autonome
3- Bras télescopique (à voir au vu du temps restant)

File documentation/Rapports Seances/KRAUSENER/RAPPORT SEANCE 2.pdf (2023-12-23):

## RAPPORT SEANCE 2 :

Durant cette semaine, nous avons beaucoup avancé, plus que les objectifs que nous nous étions fixés. Le travail a été judicieusement partagé entre mon collègue et moi, lui s’est occupé des modules HC-12 et je me suis intéressé au fonctionnement des moteurs/cerveau moteur et à leur utilisation.

En effet, la semaine dernière, un châssis déjà monté nous avait été donné et cette semaine a donc été consacrée à la compréhension du fonctionnement de tous les éléments constituants la voiture (moteur, pont H, émetteur /récepteur HC-12…).

J’ai, personnellement, réalisé les branchements des deux moteurs et du cerveau moteur au pont H et à la carte Arduino Uno.

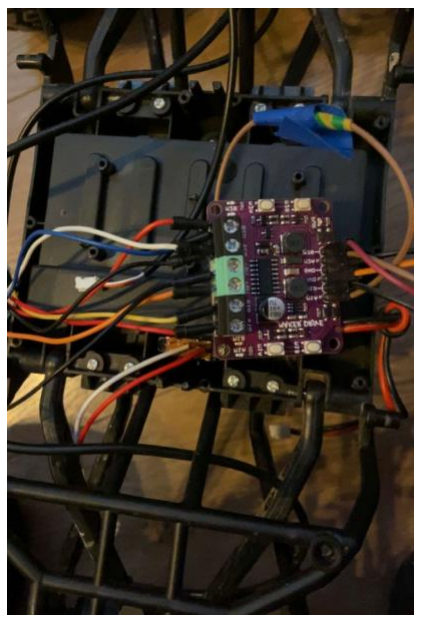
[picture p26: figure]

Durant le branchement, une erreur de ma part (mauvais branchement du pont H à la batterie) a causé la surchauffe d’un composant de celui-ci. Heureusement, Monsieur Masson nous avait confié deux d’entre eux. Ainsi, cette erreur n’a pas eu d’impact sur l’avancée du projet.

En séance, j’ai écrit le code nécessaire pour faire avancer la voiture sans télécommande (petit code qui fait avancer la voiture à 50% de sa capacité pendant 2 secondes puis qui l’arête pendant 3 secondes).

Initialisation des moteurs; Fonction faisant tourner les moteurs (valeurs allant de -255 à 255)

Concernant le récepteur/émetteur, j’ai réalisé les soudures de l’antenne et des pattes malles au composant afin de pouvoir l’utiliser sur la carte Arduino. Etant la toute première soudure que j’ai réalisée dans ma vie, l’aide du personnel du Fablab a été d’une grande utilité.

L’objectif des prochains jours/semaines, sera d’établir une liaison entre l’Arduino et la manette grâce au module HC-12 et du travail de Theo. Une fois les modules liés, la télécommunication entre la voiture et la télécommande sera simple à réaliser puisque, aussi bien de son côté que du miens, les notions


nécessaires ont été comprises. La tâche complexe sera donc, vous l’aurez compris, de lier les deux modules et de transmettre les informations.

Une fois cette tâche achevée, un travail de calibrage et de répartition du poids de la voiture sera nécessaire au vu de l’objectif fixé : aller vite.

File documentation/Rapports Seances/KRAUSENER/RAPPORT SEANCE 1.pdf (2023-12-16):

KRAUSENER Alexandre G1 PeiP2

## RAPPORT SEANCE 1 (15/12/23) :

Pendant cette séance, nous avons passé beaucoup de temps pour chercher des pièces. Personnellement, j’ai cherché un moteur capable de délivrer la vitesse nécessaire pour faire avancer notre voiture et répondre à notre cahier des charges.

Le moteur présenté ici pouvait satisfaire nos attentes puisque, voulant faire avancer notre voiture à plus de 30km/h, la force d’entrainement du moteur (P=F x V sans prendre en compte le poids de la
voiture et les frottements) est assez élevée.
Après | avoir | effectué
quelques recherches, nous
avons demandé à un
enseignant de commander
les pièces nécessaires pour la conception de de notre
voiture RC.


Cependant, notre enseignant nous à déconseiller de réaliser nous-même notre voiture car la direction poserait des problèmes techniques trop complexe à résoudre (présence d’un différentiel, pèces mécaniques technique…). Nous avons donc reçu un châssis déjà réaliser.


Celui-ci est composé de deux moteurs, un cerveau moteur et de toutes les pièces mécaniques nécessaire pour faire tourner notre véhicule. L’objectif des prochaines séances sera donc de comprendre comment faire avancer la voiture, effectuer les branchements, et de gérer la communication avec la télécommande fournie elle aussi.


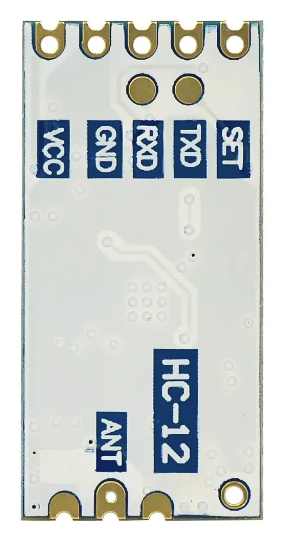
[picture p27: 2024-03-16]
documentation/HC-12 Doc/pins.png

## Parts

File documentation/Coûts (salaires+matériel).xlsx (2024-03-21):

Composants | Référence | Quantité | Prix unitaire(€) | Sous-total(€) | membre | Statut | Salaire horaire(€) | Heures travaillées(H) | Sous-total(€)
Châssis | inconnue | 1 | 50 | 50 | Alexandre | Ingénieur | 23 | 50 | 1150
Batterie | Lipo ZOP Power 2200mAh 30C 3S | 1 | 26.39 | 26.39 | Théo | Ingénieur | 23 | 60 | 1380
moteurs | INJORA 550 RC Brossé Etanche Moteur 35T | 3 | 15.28 | 45.84
ponts en H | LN298N | 2 | 3.39 | 6.78 | Total | / | / | 110 | 2530
modules RF | HC12 | 2 | 4.99 | 9.98
Carte électronique 1 | Arduino Uno R3 | 1 | 10.99 | 10.99
Carte électronique 2 | Arduino Esplora | 1 | 51.79 | 51.79
Total(€) | / | / | 162.83 | 201.77

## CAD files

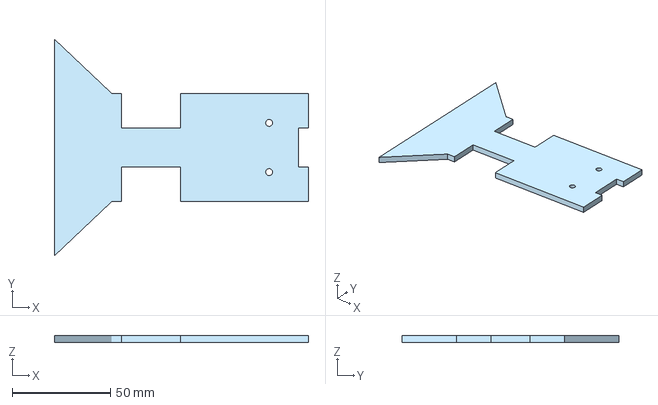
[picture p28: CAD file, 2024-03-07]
3D models/planche.3mf
129.0 x 110.0 x 3.50 mm

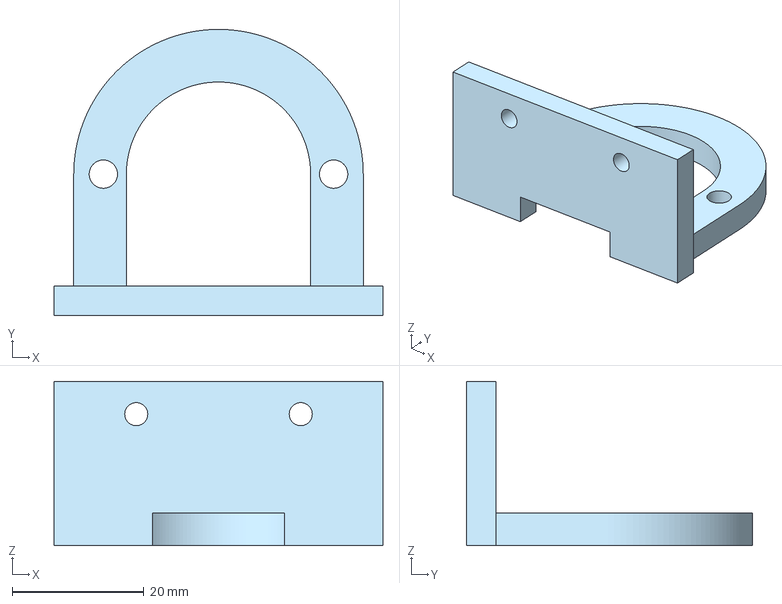
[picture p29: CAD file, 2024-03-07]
3D models/accroche moteur.3mf
50.0 x 43.5 x 25.0 mm

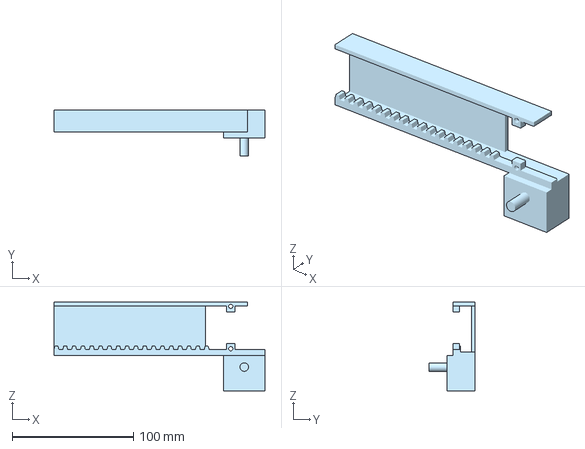
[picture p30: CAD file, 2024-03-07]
3D models/courroie.3mf
174.3 x 38.0 x 73.3 mm

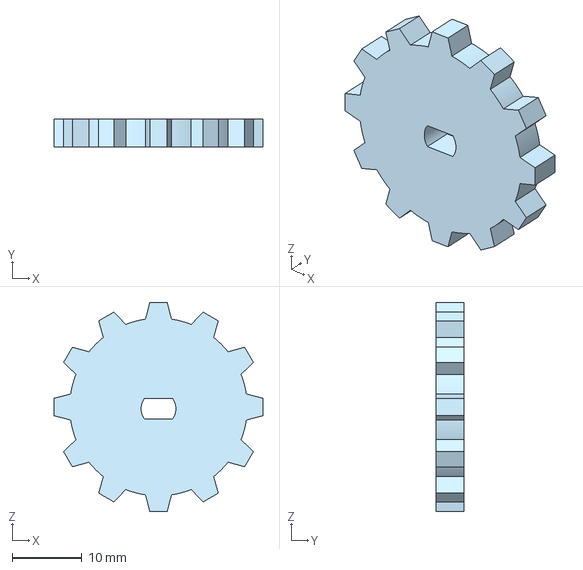
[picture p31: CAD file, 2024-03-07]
3D models/gear.3mf
30.0 x 4.00 x 30.0 mm

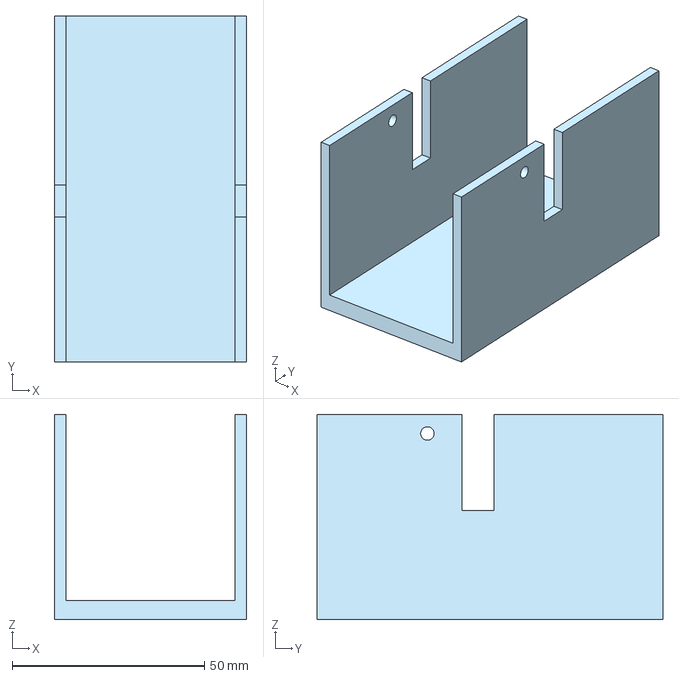
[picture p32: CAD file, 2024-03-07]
3D models/Fixation.3mf
50.0 x 90.0 x 53.5 mm

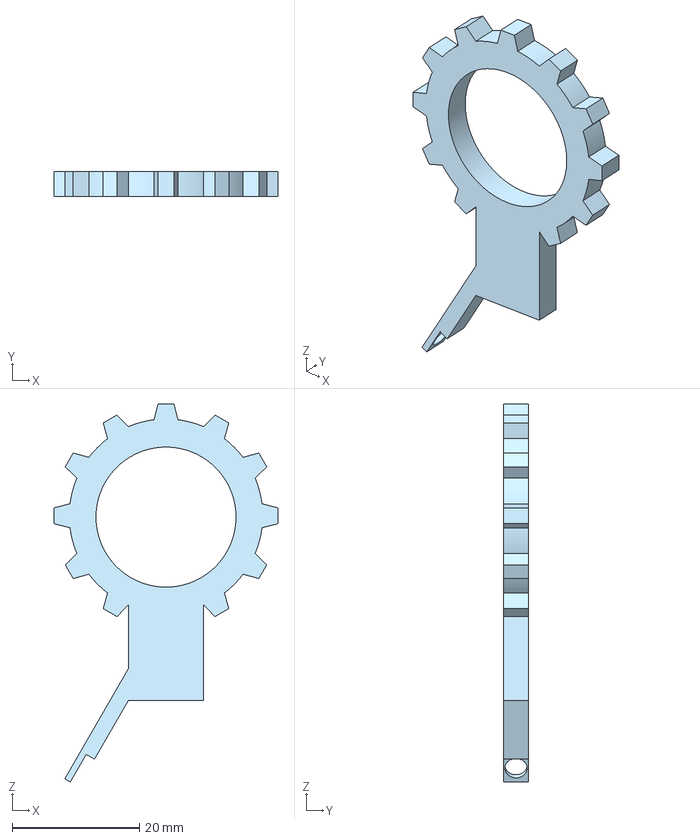
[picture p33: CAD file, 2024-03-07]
3D models/Pince 1 rotation.3mf
35.1 x 4.00 x 59.4 mm

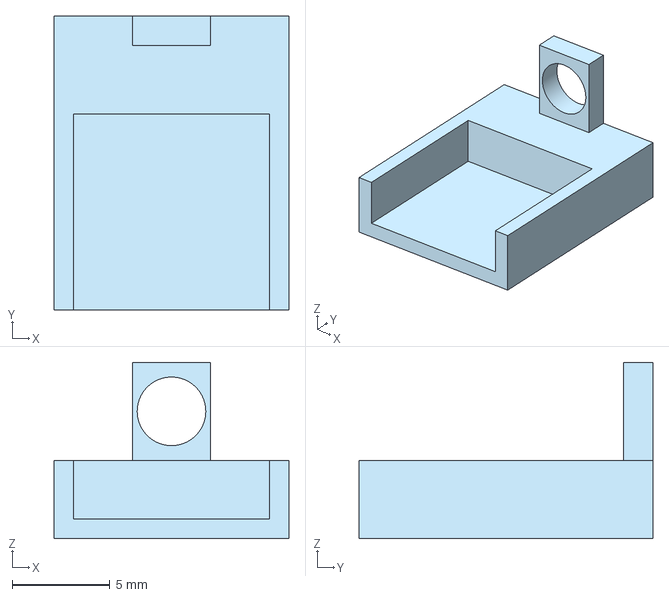
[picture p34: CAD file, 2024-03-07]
3D models/PINCE 2.3mf
12.0 x 15.0 x 9.00 mm

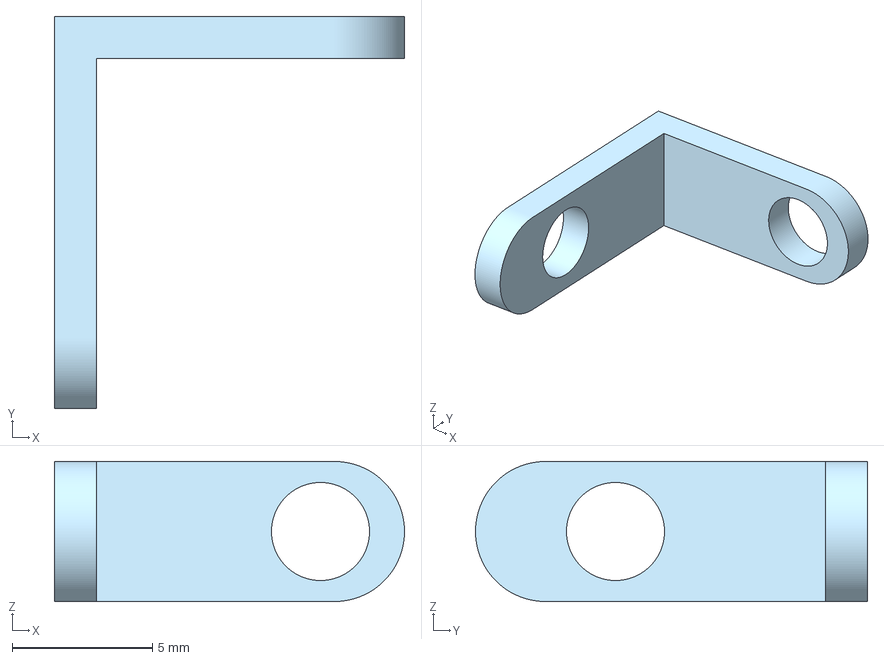
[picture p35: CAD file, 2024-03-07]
3D models/FIXE.3mf
12.5 x 14.0 x 5.00 mm

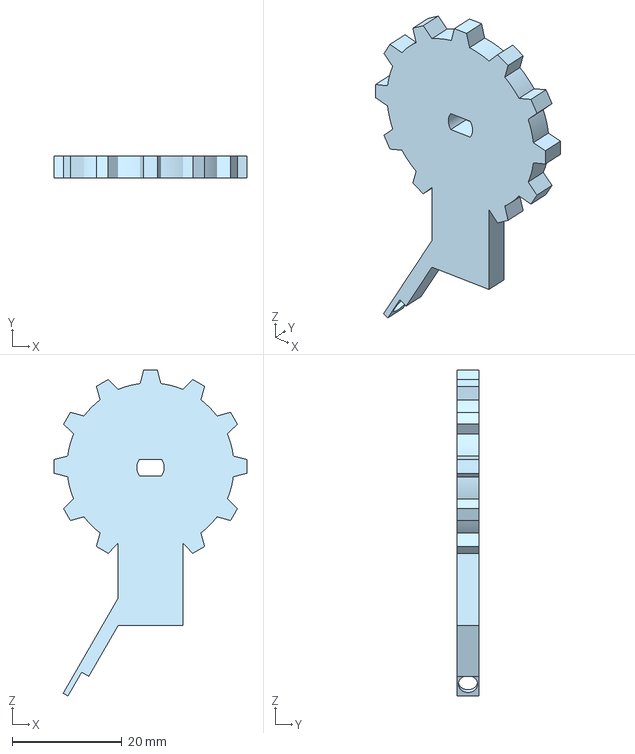
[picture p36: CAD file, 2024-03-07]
3D models/PINCES 1 moteur.3mf
35.1 x 4.00 x 59.4 mm

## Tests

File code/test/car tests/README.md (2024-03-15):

#### Vous trouverez ici l'ensemble des tests visant à diriger la voiture (plus ou moins fructueux)

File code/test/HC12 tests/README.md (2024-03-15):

#### Ici se trouvent les tests concernant l'utilisation seule des modules Radio-Fréquence HC-12

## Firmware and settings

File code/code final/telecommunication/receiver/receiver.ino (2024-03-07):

//#include <L298NX2.h>

#include <SoftwareSerial.h>

// Pin definition
const unsigned int EN_A = 3;
const unsigned int IN1_A = 4;
const unsigned int IN2_A = 5;

const unsigned int IN1_B = 6;
const unsigned int IN2_B = 7;
const unsigned int EN_B = 9;

const unsigned int IN1_C = 12;
const unsigned int IN2_C = 13;
const unsigned int EN_C= 6;




// Initialize both motors
//L298NX2 motors(EN_A, IN1_A, IN2_A, EN_B, IN1_B, IN2_B);

//Configure the software Serial blabla
SoftwareSerial HC12(10, 11); // HC-12 TX Pin, HC-12 RX Pin

//variables
char incomingByte;
String readBuffer;
boolean start = false;
int roll=0;
int direction = 0;
char action;
int value;

void setup() {
  Serial.begin(9600);             // Serial port to computer
  HC12.begin(9600);               // Serial port to HC12
  pinMode(EN_A,OUTPUT);
  pinMode(IN1_A,OUTPUT);
  pinMode(IN2_A,OUTPUT);
  pinMode(EN_B,OUTPUT);
  pinMode(IN1_B,OUTPUT);
  pinMode(IN2_B,OUTPUT);
  pinMode(EN_C,OUTPUT);
  pinMode(IN1_C,OUTPUT);
  pinMode(IN2_C,OUTPUT);
}

void rolling(int roll){
  if(roll>=0){
    digitalWrite(IN1_A,LOW);
    digitalWrite(IN2_A,HIGH);
    digitalWrite(IN1_B,LOW);
    digitalWrite(IN2_B,HIGH);
  }
  else{
    digitalWrite(IN1_A,HIGH);
    digitalWrite(IN2_A,LOW);
    digitalWrite(IN1_B,HIGH);
    digitalWrite(IN2_B,LOW);
  }
  analogWrite(EN_A, abs(roll));
  analogWrite(EN_B, abs(roll));
}

void turning (int direction){
  if(direction>=0){
  digitalWrite(IN1_C,LOW);
  digitalWrite(IN2_C,HIGH);
  }
  else{
    digitalWrite(IN1_C,HIGH);
    digitalWrite(IN2_C,LOW);
  }
  analogWrite(EN_C, abs(direction));
}

/*void turning(int direction){

}*/

void loop() {
  //Serial.println(HC12.read());

  readBuffer = "";
  start = false;
  // Reads the incoming data
  while (HC12.available()) {             // If HC-12 has data
    incomingByte = HC12.read();          // Store each icoming byte from HC-12
    delay(5);
    // Reads the data between the start "s" and end marker "e"
    if (start == true) {
      if (incomingByte != 'e') {
        readBuffer += char(incomingByte);    // Add each byte to ReadBuffer string variable
      }
      else {
        start = false;
      }
    }
    // Checks whether the received message statrs with the start marker "s"
    else if ( incomingByte == 's') {
      start = true; // If true start reading the message
    }
  }

  if (readBuffer!=""){
  Serial.println(readBuffer);
  int index = readBuffer.indexOf('d');
  roll = readBuffer.substring(0, index).toInt();
  direction = readBuffer.substring(index+1).toInt();
  Serial.println(roll);
  Serial.println(direction);
  rolling(roll);  //envoie la valeur de roll aux moteurs
  //motors.setSpeedB(roll); //envoie la valeur reçue au servo
  turning(direction);

  }

}

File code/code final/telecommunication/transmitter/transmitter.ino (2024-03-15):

#include <SoftwareSerial.h>
#include <Esplora.h>
//SoftwareSerial HC12(14,15); // HC-12 TX Pin, HC-12 RX Pin
SoftwareSerial HC12(16,15); // HC-12 TX Pin, HC-12 RX Pin


int potValue = 0;
int joyValueX = 0;
int joyValueY = 0;
boolean buttonValue = false;
int motorPower = 0;
int roll = 0;
int direction = 0;

void setup() {
  Serial.begin(9600);             // Serial port to computer
  HC12.begin(9600);               // Serial port to HC12

}

void loop() {     
  //digitalWrite(14,LOW);

  potValue = Esplora.readSlider();
  joyValueX = Esplora.readJoystickX();
  joyValueY = Esplora.readJoystickY();
  buttonValue = Esplora.readButton(SWITCH_UP);
  motorPower = map(potValue, 0, 1023, 20, 100); //fonction qui détermine à quel pourcentage de puissance le moteur tourne

  if(abs(joyValueX) < 10){direction = 0;}   //Correction de la sensibilité du Joystick en X
  else{direction=map(joyValueX,-512,512,255,-255);}

  if(abs(joyValueY)<10){roll=0;}
  else{roll = map(joyValueY,-512,512,255,-255)*motorPower/100;}
  
  Serial.println('s'+String(roll) + 'd' + String(direction)+'e');
  HC12.println('s'+String(roll) + 'd' + String(direction)+'e');


  delay(10);
  
}

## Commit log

2023-12-16 rapport séance 1 krausener
    [PLANNING.xlsx]
2023-12-16 Update CIMINO.md
    test de l'hyperlien
2023-12-16 Update CIMINO.md
    markdown c de la merde
2023-12-27 Update RAPPORTSEANCE3.md
    add retours à la ligne
2023-12-29 finalisation et test du code
    la voiture obeis, finito, il faudra rajouter un bit de contrôle mais flemme
2024-02-19 gnagna projet de merde
2024-03-11 Update PROJET ARDUINO oral.pptx
2024-03-16 rename impression to 3D models
    [FIXE.3mf, Fixation.3mf, PINCE 2.3mf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]
2024-03-20 ecxel des plannings
    [PLANNING.xlsx, planning initial (t=0).xlsx]
2024-03-21 rapport+fichiers tiers
    finito pipo
    [Coûts (salaires+matériel).xlsx, planning prévisionnel.xlsx]
